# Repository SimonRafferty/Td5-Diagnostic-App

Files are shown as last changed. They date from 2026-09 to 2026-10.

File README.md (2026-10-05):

# Td5-Diagnostic-App

An open-source OBD2 scanner for Land Rover Td5 vehicles - live data, fault codes, and the parameters unique to the Td5, at a fraction of the cost of a NanoCom. Compatible with ELM327 apps, with its own built-in web app and an Android app.

An OBD2 scanner has become an essential part of most vehicle owners' toolkit. However, if you own a Land Rover Td5, your options are limited and expensive.

NanoCom from BlackBox Solutions is the go-to for most people, but it's pricey. If you want to re-map your engine it's good value - but most people just want to read live data and read/clear Diagnostic Trouble Codes (DTCs). On any other vehicle a simple ELM327 scanner and a phone app cost next to nothing; Td5 owners have had to fork out £600+ for a NanoCom. This project is a low-cost alternative - one you can leave in the Land Rover without worrying that it'll get wet, damaged or stolen.

Along with the matching hardware (a K-Line interface + ESP32-S3), it plugs into the Td5 diagnostic socket and emulates an ELM327 scanner. Unlike generic OBD2 apps, the app here also shows the information unique to the Td5, and reads and clears DTCs - completely free and open source.

## Updating your dongle

**[Click here to update your dongle to the latest firmware](https://simonrafferty.github.io/Td5-Diagnostic-App/flash/)**

Open the link in **Google Chrome** or **Microsoft Edge** on a computer, plug the dongle into the computer with a USB-C cable, and click **Install** - the page walks you through it in four simple steps. Updating keeps your stored fuel-economy history. (The version your dongle is running is shown at the bottom of the app.)

## Connecting to the Dongle

The dongle hosts the whole app itself, so the main way to use it is to open a web page it serves over its own WiFi - there's nothing to install.

### The main way - web page over WiFi (works on everything)

1. Connect your phone, tablet or PC to the open WiFi network **`OBDII`** (no password).
2. Open a browser and go to **http://11.1.1.1**.

That's it - the app loads straight from the dongle and connects itself. No app to install, no Bluetooth pairing. This works the same on **iPhone, iPad, Android and PC**.

> While you're on the dongle's WiFi your device has no internet, so online fault-code look-ups won't work. On Android you can connect over Bluetooth instead (see below) to keep your internet.

### iPhone and iPad

The WiFi web page above is the **only** way to connect on an iPhone or iPad - Safari can't use Bluetooth. Just join **`OBDII`** and open **http://11.1.1.1**; Safari handles it perfectly.

### Android - WiFi or the app

On Android you have two options:

- **Web page over WiFi** - exactly as above: join **`OBDII`** and open **http://11.1.1.1**. Nothing to install.
- **The Android app over Bluetooth** - install the [APK](Td5-Diagnostics-debug.apk) (see *Installing the Android App* below), open it, tap **Connect** and choose **OBDII**. Because this connects over Bluetooth, your phone stays on its normal mobile data, so online DTC look-ups keep working.

> The dongle serves **one connection at a time** - whichever you connect with first (WiFi or Bluetooth) is used for that session, and the other is disabled until the dongle restarts (which it does each time the engine starts).

## Installing the Android App

The app isn't on the Google Play Store yet - I'll upload it there in due course to make installing and updating easy. In the meantime you can "side-load" it directly, which only takes a minute:

1. On your Android phone or tablet, download [**Td5-Diagnostics-debug.apk**](Td5-Diagnostics-debug.apk) from this repository (open the link, then tap the download button).
2. Open it from your Downloads. Android will warn you it's from an "unknown source" - this is normal for any app installed outside the Play Store.
3. Follow the prompt to Settings and allow "Install unknown apps" for your browser (or Files app), then go back and tap Install.
4. Open Td5 Diagnostics, tap **Connect**, and choose **OBDII** from the list.

Because this is a debug build it isn't signed for the Play Store, so that "unknown source" warning is expected and safe to accept. Once the Play Store version is live I'll link to it from here (Google can take a while to approve an app).

## What the App Does

There are four simple tabs - swipe left and right to move between them:

- **Fault Codes** - read and clear DTCs, each with a plain-English description of the Td5 fault and a link to look it up online. Once connected it also shows the vehicle's VIN and current fuel-map name (where the ECU provides them).
- **Available Data** - every parameter the ECU will give you, including the extras unique to the Td5 - injector balance, accelerator tracks, EGR and wastegate, glow-plug and relay states, sensor voltages, idle-speed error and more - plus calculated values like turbo boost and live fuel economy (instantaneous, a rolling 50-mile average (paused while stationary), and trip fuel used). Tick what you'd like to see and/or graph, and pick your units.
- **Live Data** - your chosen parameters, updating live.
- **Graphs** - up to four auto-scaling charts so you can watch how things move (boost, temperatures, injector balance and so on).

### Logging

On the **Available Data** tab there's a single **Log displayed items to CSV** tick box. Tick it and everything you've chosen to display is written to a timestamped CSV file, in your selected units - handy for looking at a fault after a drive, or comparing readings over time.

- **In the Android app**, the file is saved straight to the phone's **Documents** folder as `Td5_Log_<date>_<time>.csv` (open it with the Files app, or copy it off over USB).
- **In the web page**, tick to start, then use **Download log now** - or simply untick - to save the file to your browser's Downloads.

## Screenshots

| Fault Codes | Available Data |
|:---:|:---:|
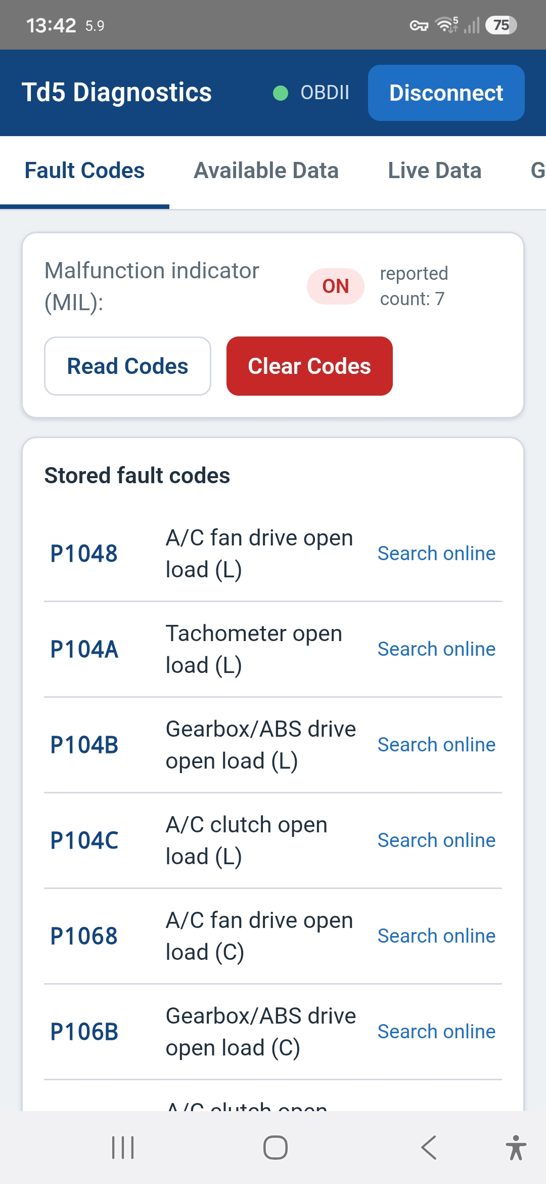
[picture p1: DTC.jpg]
Fault Codes screen
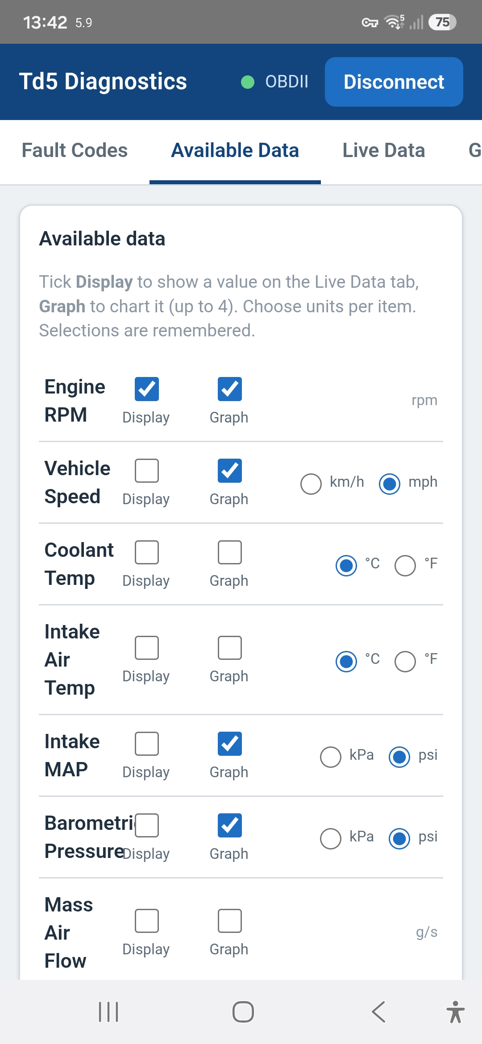
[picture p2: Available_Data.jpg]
Available Data screen
|  |  |
| **Live Data** | **Graphs** |
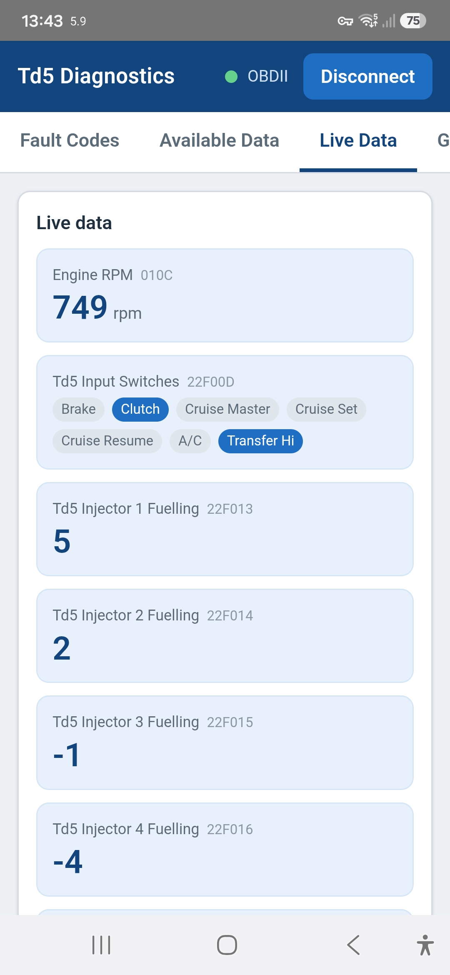
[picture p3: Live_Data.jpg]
Live Data screen
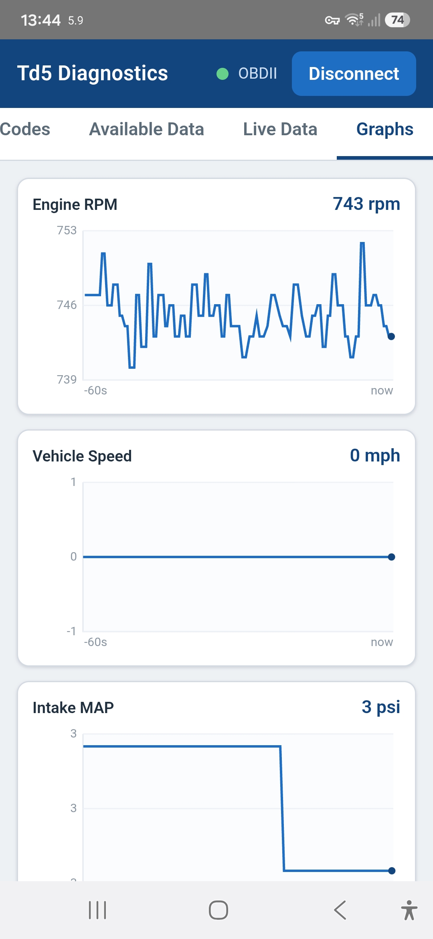
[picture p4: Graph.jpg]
Graphs screen
|  |  |

## What's in this Repository

| Item | Contents |
|---|---|
| `Firmware/` | The ESP32-S3 dongle firmware (Arduino). It turns the K-Line interface into an ELM327 that apps can talk to over **Bluetooth**, and also hosts the web app over **WiFi** (open `OBDII` network, http://11.1.1.1). |
| `App/` | The Android app project (built with Capacitor) used to produce the APK. |
| `Hardware/` | The complete dongle design: PCB gerbers, schematic, BOM, pick-and-place, Altium source, and 3D-printable case halves. |
| [`Td5-Diagnostics-debug.apk`](Td5-Diagnostics-debug.apk) | The ready-to-install Android app. |

## The Hardware

The dongle is an ESP32-S3 plus a simple K-Line interface (an L9637D transceiver and a little protection circuitry). It connects to the Td5 diagnostic line - OBD pin 7, or pin B18 on the ECU. Everything needed to build one is in the [`Hardware`](Hardware) folder:

- **PCB** - send [`Td5_OBD2_Gerber.zip`](Hardware/Td5_OBD2_Gerber.zip) to any board house to have the board made.
- **Assembly** - [`Td5_OBD2_BOM.csv`](Hardware/Td5_OBD2_BOM.csv) (bill of materials) and [`Td5_OBD2_PickAndPlace.xlsx`](Hardware/Td5_OBD2_PickAndPlace.xlsx).
- **Design source** - the full [schematic (PDF)](Hardware/Td5_OBD2_Schematic.pdf) and the editable [Altium project](Hardware/Td5_OBD2_Altium.zip).
- **Enclosure** - two 3D-printable case halves: [left](Hardware/Dongle%203D%20Print%20Shell%20Left.STEP) and [right](Hardware/Dongle%203D%20Print%20Shell%20Right.STEP) (STEP).

## Building From Source

**Firmware:** open `Firmware/Td5_Diagnostic/Td5_Diagnostic.ino` in the Arduino IDE, select the **XIAO_ESP32S3** board and upload. You'll need the *EspSoftwareSerial* and *NimBLE-Arduino* libraries (WiFi and DNSServer are built into the ESP32 core). The web app the dongle serves over WiFi is embedded as `webapp_html.h`, already in the repo, so it builds as-is. If you change the app, regenerate that header with `python Firmware/tools/embed_webapp.py` before rebuilding.

**Publishing a firmware update** to the web flasher: run `python Firmware/tools/publish_firmware.py`. It stamps a date-based version into `config.h`, re-embeds the app, compiles against the Arduino IDE's sketchbook libraries and copies the four flash images plus `manifest.json` into `flash/`. Commit and push, and the update page serves the new version about a minute later.

**Android app:** the app is `App/www/index.html` plus a small Bluetooth bridge that lets the native APK reach the phone's Bluetooth stack (an Android WebView has no Web Bluetooth). To rebuild the APK, run `npm install` in the `App` folder, then `npm run sync`, and build with Android Studio (or `gradlew assembleDebug`).

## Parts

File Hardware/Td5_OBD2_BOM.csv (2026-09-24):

No. | Quantity | Comment | Designator | Footprint | Value | Manufacturer Part | Manufacturer | Supplier Part | Supplier
1 | 3 | 330nF | C1,C2,C3 | C0603 | 330nF | TCC0603X7R334K500CT | CCTC(三环) | C282682 | LCSC
2 | 1 | 100nF | C4 | C0402 | 100nF | CC0402KRX7R7BB104 | YAGEO(国巨) | C60474 | LCSC
3 | 1 | ZMM27V | D1 | LL-34_L3.5-W1.5-RD |  | ZMM27V | JSMSEMI(杰盛微) | C2857252 | LCSC
4 | 2 | SS34 | D2,D3 | SMA_L4.3-W2.6-LS5.2-RD |  | SS34 | MDD(辰达半导体) | C8678 | LCSC
5 | 1 | OBD2 | J*1 | OBD2_Male_R/A_Case https://www.aliexpress.com/item/1005006438089634.html
6 | 1 | 47kΩ | R1 | R0402 | 47kΩ | 0402WGF4702TCE | UNI-ROYAL(厚声) | C25792 | LCSC
7 | 1 | 1kΩ | R2 | R0603 | 1kΩ | FRC0603F1001TS | FOJAN(富捷) | C2907002 | LCSC
8 | 1 | 510R | R3 | R0603
9 | 1 | 10kΩ | R4 | R0402 | 10kΩ | FRC0402F1002TS | FOJAN(富捷) | C2906861 | LCSC
10 | 1 | 51kΩ | R5 | R0402 | 51kΩ | 1RC0402J0513 | SAE(世盟/世爱) | C54531106 | LCSC
11 | 1 | 20kΩ | R6 | R0402 | 20kΩ | TNPW040220K0BEED | VISHAY(威世) | C844261 | LCSC
12 | 1 | TLV3691IDCKR | U1 | SC-70-5_L2.1-W1.3-P0.65-LS2.1-BR |  | TLV3691IDCKR | TI(德州仪器) | C180352 | LCSC
13 | 1 | K7805-500R3 | U2 | PWRM-TH_3P-L11.5-W7.6-P2.54_R-785.0-0.5 |  | K7805-500R3 | YLPTEC(易川) | C2992390 | LCSC
14 | 1 | E-L9637D013TR | U3 | SOIC-8_L4.9-W3.9-P1.27-LS6.0-BL |  | E-L9637D013TR | ST(意法半导体) | C153038 | LCSC
15 | 1 | XIAO ESP32S3 | U4 | COMM-SMD_KQ-2801_V106 |  | XIAO ESP32C3 | null | C19189385 | LCSC

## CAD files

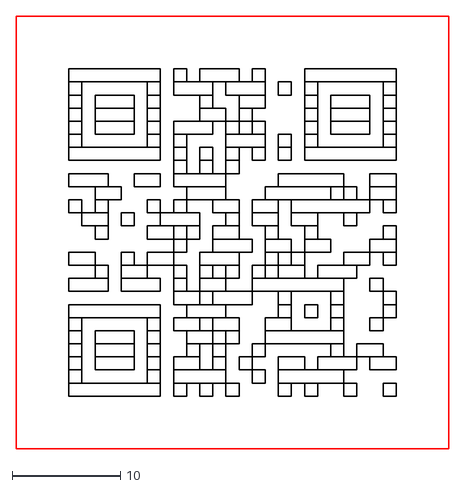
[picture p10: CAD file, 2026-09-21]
Hardware/Td5_QR_Code.dxf
40.0 x 40.0

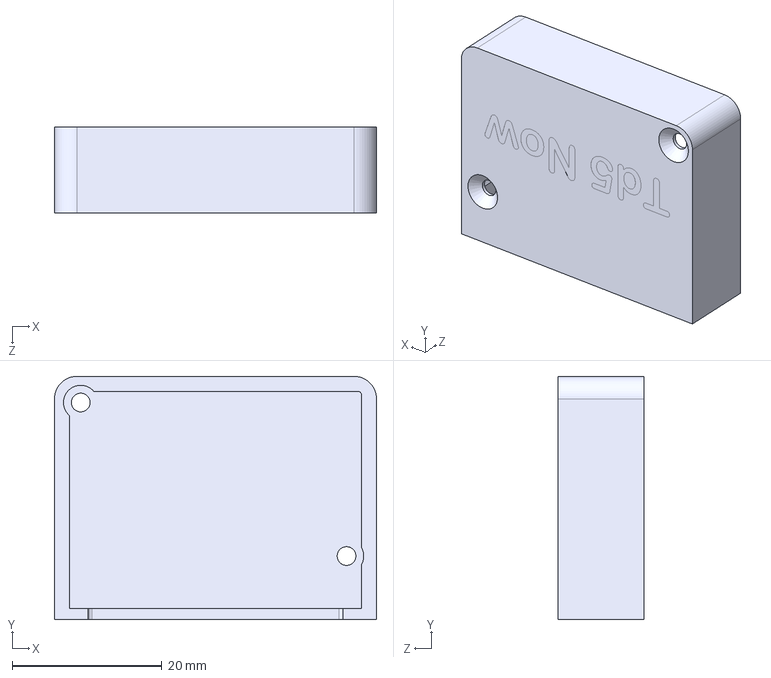
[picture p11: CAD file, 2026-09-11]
Hardware/Dongle 3D Print Shell Right.STEP
43.0 x 32.5 x 11.5 mm

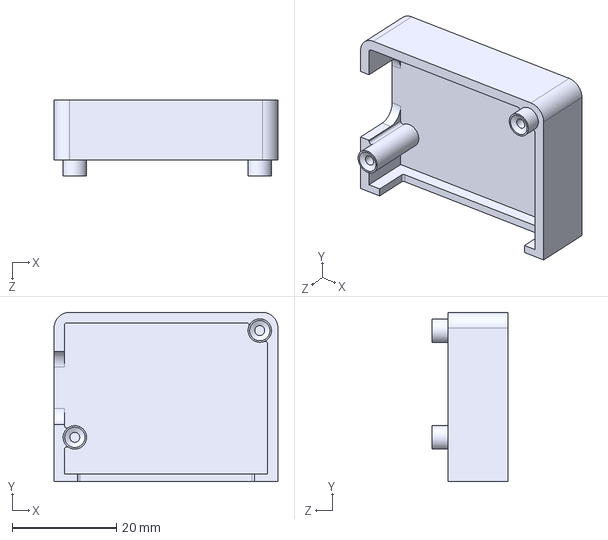
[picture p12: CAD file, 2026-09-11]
Hardware/Dongle 3D Print Shell Left.STEP
43.0 x 32.5 x 14.5 mm

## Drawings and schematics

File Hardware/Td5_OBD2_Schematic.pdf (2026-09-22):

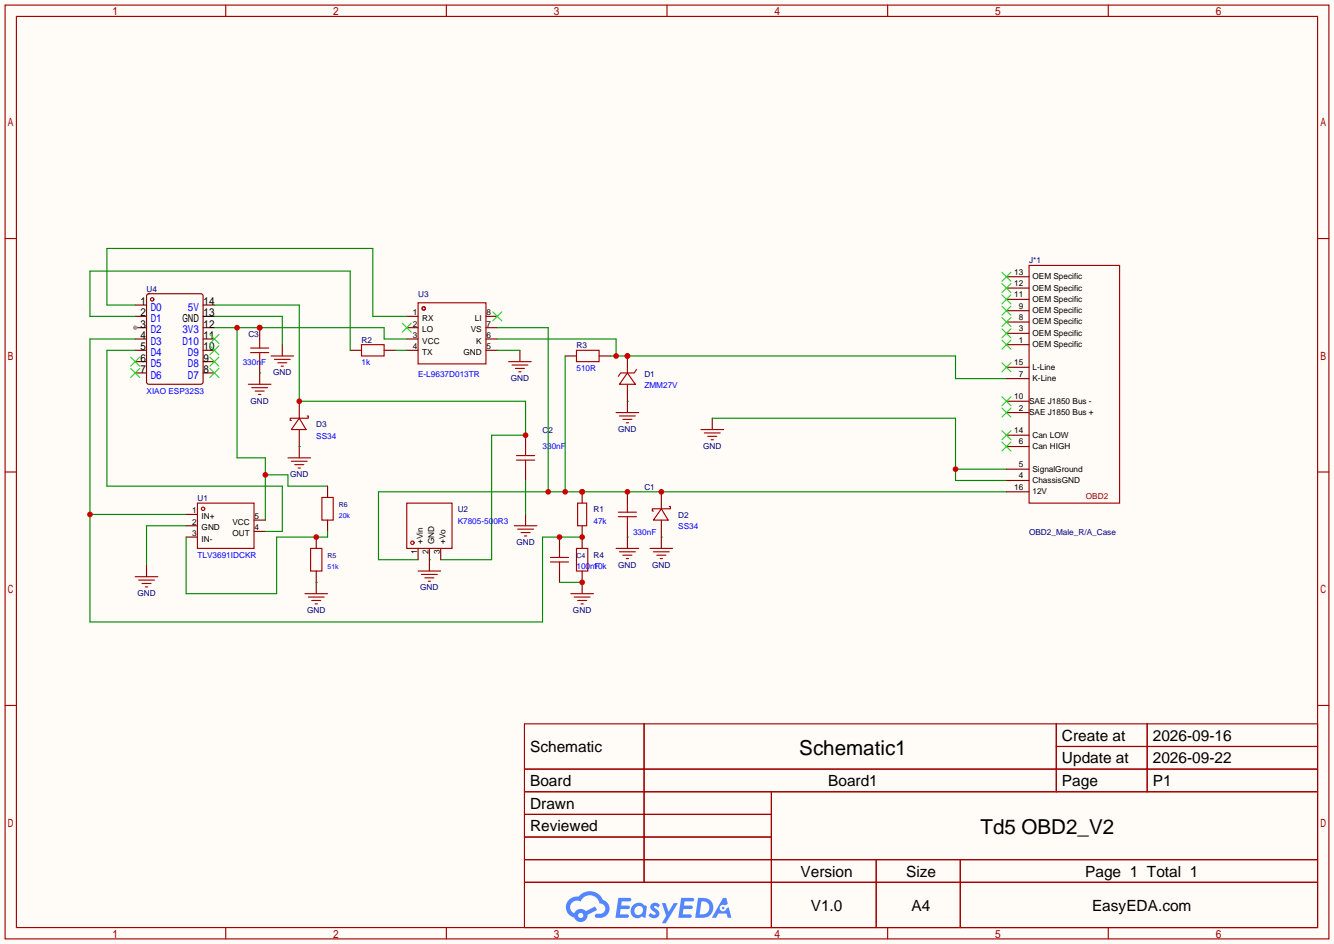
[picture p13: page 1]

Schematic | Schematic1 | Create at | 2026-09-16

Update at | 2026-09-22

Board | Board1 | Page | P1
Drawn | | Td5 OBD2_V2
Reviewed

Version | Size | Page 1 Total 1
V1.0 | A4 | EasyEDA.com

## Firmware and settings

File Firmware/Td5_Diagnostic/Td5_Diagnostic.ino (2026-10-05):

/*
 * Td5_Diagnostic_V2.ino - Land Rover Td5 Diagnostic (ELM327) dongle - V2 hardware
 * ===============================================================================
 *
 * Identical to Td5_Diagnostic EXCEPT for the V2 PCB power management. The ECU /
 * ELM327 / BLE / OBD stack is UNCHANGED - keep it in sync with Td5_Diagnostic;
 * any protocol/decode change must be applied to BOTH sketches.
 *
 * V2 power management (comparator-gated deep sleep, ported from Td5_ESPNow_V2):
 *   - D3 (GPIO4) = battery-divider sense (ADC, x5.7). Serial-debug only.
 *   - D4 (GPIO5) = TLV3691 comparator output, HIGH when Vbat > ~13.5V
 *                  (engine started / alternator charging). EXT0 deep-sleep wake.
 *   - Wake  : deep sleep -> D4 rising HIGH (engine start).
 *   - Sleep : after INACTIVITY_TIMEOUT_MS (5 min) of no ECU comms AND D4 == LOW.
 *   The dongle wakes on ENGINE START, not ignition-on alone (~12.4V keeps D4 LOW).
 *
 * Pin assignments CONFIRMED on the V2 PCB (2026-09-20): D3=GPIO4 (PIN_VBAT_SENSE),
 * D4=GPIO5 (PIN_CHG_SENSE) - see config.h.
 * Set ENABLE_DEEP_SLEEP 0 in config.h for bench work on hardware without the
 * comparator (a floating D4 could otherwise trigger a random sleep).
 *
 * Board: Seeed XIAO ESP32-S3   FQBN: esp32:esp32:XIAO_ESP32S3
 */

#include "config.h"
#include "vehicle_data.h"
#include "data_provider.h"
#include "obd_pids.h"
#include "elm327.h"

#if ENABLE_DEEP_SLEEP
  #include <esp_sleep.h>          // deep sleep + wake-cause
  #include "driver/rtc_io.h"      // rtc_gpio_* (wake-pin pull config)
#endif

#include "transport_arbiter.h"
#if ENABLE_WIFI_ELM
  #include "wifi_server.h"
#endif
#if ENABLE_WIFI_WEBAPP
  #include "web_server.h"
#endif
#if ENABLE_BLE_ELM
  #include "ble_server.h"
#endif

#if !ENABLE_WIFI_ELM && !ENABLE_WIFI_WEBAPP && !ENABLE_BLE_ELM
  #error "Enable at least one transport (ENABLE_BLE_ELM / ENABLE_WIFI_WEBAPP / ENABLE_WIFI_ELM) in config.h"
#endif

#if DATA_SOURCE_SIM
  #include "sim_provider.h"
  static SimProvider provider;
#else
  #include "td5_provider.h"
  static Td5Provider provider;
#endif

// The stack above the provider is identical in both phases and both transports.
static ObdTranslator obd(provider);
static Elm327        elm(obd);

// One-radio-per-session lock shared by the BLE and WiFi servers (transport_arbiter.h).
static TransportArbiter arbiter;

#if ENABLE_WIFI_ELM
static WifiElmServer wifiServer(elm, ELM_TCP_PORT);
#endif
#if ENABLE_WIFI_WEBAPP
static WebAppServer  webServer(elm, arbiter, WEBAPP_HTTP_PORT);
#endif
#if ENABLE_BLE_ELM
static BleElmServer  bleServer(elm, arbiter);
#endif

// ============================================================================
// V2 POWER MANAGEMENT (comparator-gated deep sleep)
// ============================================================================
#if ENABLE_DEEP_SLEEP

// RTC memory survives deep sleep; reset only on a true power cycle.
RTC_DATA_ATTR uint32_t bootCount = 0;

// Single activity timestamp driving the sleep decision. Reset on ECU comms / charging.
static unsigned long lastActivityMs = 0;

// Power-management runtime state (all session-only; nothing persisted to flash).
static uint16_t g_vbatMv    = 0;      // latest measured battery voltage (mV), refreshed ~2s
static bool     g_fromSleep = false;  // this boot woke from deep sleep (vs a true power-on)
static bool     g_compOk    = false;  // D4 reads LOW while off-charge (healthy) - diagnostic/display only

// Battery voltage on D3 (GPIO4) via the 47k/10k divider, in millivolts.
// Diagnostic / Serial only - never enters the OBD data path.
static uint16_t readBatteryVoltage() {
  uint32_t acc = 0;
  for (uint8_t i = 0; i < VBAT_ADC_SAMPLES; i++)
    acc += analogReadMilliVolts(PIN_VBAT_SENSE);   // eFuse-calibrated mV at the pin
  return (uint16_t)(((float)acc / VBAT_ADC_SAMPLES) * VBAT_DIVIDER_RATIO);
}

// Called only once the engine is judged off (Vbat < CHARGE_MV, ECU quiet). The WAKE
// source is decided from the LIVE comparator level read here:
//   D4 LOW  -> healthy: wake on the D4 rising edge (engine start) + a long backstop
//   D4 HIGH -> can't trust it (stuck-high fault, or genuinely charging): poll in 10s
static void enterSleepMode() {
#if ENABLE_WIFI_ELM || ENABLE_WIFI_WEBAPP
  WiFi.disconnect(true);
  WiFi.mode(WIFI_OFF);          // kill the AP radio before sleeping (covers the web-app AP too)
#endif
  esp_sleep_disable_wakeup_source(ESP_SLEEP_WAKEUP_ALL);   // clean slate - RTC config survives sleep

  if (digitalRead(PIN_CHG_SENSE) == LOW) {
    Serial.printf("\n*** Deep sleep (Boot #%u) -> wake on engine start (D4 rising), %lumin backstop ***\n",
                  bootCount, (unsigned long)(LONG_SLEEP_US / 60000000ULL));
    Serial.flush();
    esp_sleep_enable_ext0_wakeup(PIN_CHG_SENSE, 1);   // D4 is LOW now -> fires on the LOW->HIGH edge
    rtc_gpio_pullup_dis(PIN_CHG_SENSE);               // TLV3691 is push-pull; no internal pull
    rtc_gpio_pulldown_dis(PIN_CHG_SENSE);
    esp_sleep_enable_timer_wakeup(LONG_SLEEP_US);      // safety backstop only
  } else {
    Serial.printf("\n*** Deep sleep (Boot #%u) -> re-check in %lus (D4 HIGH, can't wake on it) ***\n",
                  bootCount, (unsigned long)(SHORT_SLEEP_US / 1000000ULL));
    Serial.flush();
    esp_sleep_enable_timer_wakeup(SHORT_SLEEP_US);
  }

  esp_deep_sleep_start();   // ESP32 resets on wake - never returns
}

// Sleep after INACTIVITY_TIMEOUT_MS of no ECU comms AND battery voltage below the
// charge threshold. The decision uses the accurate D3 reading, not the comparator.
static void checkSleepCondition() {
  // Stay awake while the alternator is charging (engine running) or the ECU is
  // still responding; keep the inactivity window fresh so a full timeout is only
  // needed once the engine actually stops.
  if (g_vbatMv >= CHARGE_MV || provider.connected()) {
    lastActivityMs = millis();
    return;
  }
  if (millis() - lastActivityMs > INACTIVITY_TIMEOUT_MS) {
    Serial.println(F("\n*** Engine off (Vbat low) + inactivity timeout - sleeping ***"));
    enterSleepMode();  // does not return
  }
}

static void vbatDebug() {
  static unsigned long lastVbatMs = 0;
  if (millis() - lastVbatMs >= VBAT_READ_INTERVAL_MS) {
    lastVbatMs = millis();
    uint16_t mv = readBatteryVoltage();
    g_vbatMv = mv;
    int d4 = digitalRead(PIN_CHG_SENSE);

    // Track comparator health for the diagnostic display only: when clearly parked
    // (off-charge), a healthy D4 reads LOW. Session-only, not persisted; the sleep
    // path reads the comparator live rather than trusting this flag.
    if (mv > 1000 && mv < LOW_BATT_MV) {
      bool ok = (d4 == LOW);
      if (ok != g_compOk) {
        g_compOk = ok;
        Serial.printf("[PWR] comparator %s off-charge -> %s wake\n",
                      ok ? "reads LOW (healthy)" : "stuck HIGH (faulty)",
                      ok ? "D4-edge" : "10s poll");
      }
    }

#if ENABLE_VBAT_DEBUG
    Serial.printf("[VBAT] D3: %u mV (%.2f V) | D4: %s | comp: %s | ECU: %s\n",
                  mv, mv / 1000.0f,
                  d4 ? "HIGH" : "low",
                  g_compOk ? "healthy" : "faulty",
                  provider.connected() ? "connected" : "-");
#endif
  }
}

static void powerMgmtSetup() {
  pinMode(PIN_CHG_SENSE, INPUT);                      // comparator out - external push-pull, no pulls
  pinMode(PIN_VBAT_SENSE, INPUT);
  analogSetPinAttenuation(PIN_VBAT_SENSE, ADC_11db);  // full-scale ~0..3.3V
  analogReadResolution(12);

  bootCount++;
  esp_sleep_wakeup_cause_t wake = esp_sleep_get_wakeup_cause();
  g_fromSleep = (wake == ESP_SLEEP_WAKEUP_TIMER || wake == ESP_SLEEP_WAKEUP_EXT0);
  g_vbatMv = readBatteryVoltage();

  const char* wc = wake == ESP_SLEEP_WAKEUP_TIMER ? "TIMER"
                 : wake == ESP_SLEEP_WAKEUP_EXT0  ? "EXT0 (engine start)"
                                                  : "power-on / reset";
  Serial.printf("Boot #%u - wake: %s - Vbat %.2fV\n", bootCount, wc, g_vbatMv / 1000.0f);
  lastActivityMs = millis();   // start the inactivity window
}

#endif // ENABLE_DEEP_SLEEP

void setup() {
  Serial.begin(DEBUG_BAUD);
  Serial.setTxTimeoutMs(0);   // never block on debug prints if no USB reader attached
  delay(300);
  Serial.println();
  Serial.println(F("=== Td5 Diagnostic (ELM327) - V2 (deep sleep) ==="));
  Serial.println(F("Firmware version: " FW_VERSION));
#if DATA_SOURCE_SIM
  Serial.println(F("Data source: SIMULATED (Phase 1 bench)"));
#else
  Serial.println(F("Data source: REAL Td5 ECU (Phase 2)"));
#endif
#if ENABLE_BLE_ELM
  Serial.println(F("Transport: BLE (advertising as \"" BLE_DEVICE_NAME "\")"));
#endif
#if ENABLE_WIFI_ELM
  Serial.println(F("Transport: WiFi AP (Torque TCP)"));
#endif
#if ENABLE_WIFI_WEBAPP
  Serial.println(F("Transport: WiFi web app (SoftAP \"" AP_SSID "\" @ 11.1.1.1, open)"));
#endif

#if ENABLE_DEEP_SLEEP
  powerMgmtSetup();
  // Woke from deep sleep but still off-charge (parked): go straight back to sleep
  // without spinning up BLE / K-line, to keep average power low.
  if (g_fromSleep && g_vbatMv < CHARGE_MV) {
    Serial.println(F("Woke off-charge -> back to sleep"));
    enterSleepMode();  // does not return
  }
#endif

  provider.begin();
#if ENABLE_WIFI_ELM
  wifiServer.begin();
#endif
#if ENABLE_WIFI_WEBAPP
  webServer.begin();    // SoftAP + captive portal + HTTP app host (shares the radio with BLE)
#endif
#if ENABLE_BLE_ELM
  bleServer.begin();
#endif
}

void loop() {
  provider.poll();      // refresh live values (non-blocking; K-line runs in its own task)
#if ENABLE_WIFI_ELM
  wifiServer.poll();    // service the WiFi ELM327 session (Torque)
#endif

  // One-radio-per-session: the first transport to get a real app connection wins;
  // shut the other down (idempotent) and keep it down until the next wake/reboot.
  // All radio teardown happens here in the main task - never in a NimBLE callback.
  Transport a = arbiter.active();
#if ENABLE_BLE_ELM
  if (a == T_WIFI) bleServer.stop();     // WiFi won -> stop BLE
  else             bleServer.poll();     // (no-op; replies are inline)
#endif
#if ENABLE_WIFI_WEBAPP
  if (a == T_BLE)  webServer.shutdown(); // BLE won -> stop the WiFi AP
  else             webServer.poll();     // serve DNS + HTTP
#endif

#if ENABLE_DEEP_SLEEP
  vbatDebug();          // periodic Serial battery print (diagnostic only)
  checkSleepCondition();// may enter deep sleep (does not return)
#endif
}

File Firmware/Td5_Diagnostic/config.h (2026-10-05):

/*
 * config.h - Build-time configuration for the Td5 Diagnostic ELM327 dongle (V2)
 *
 * ONE FLAG controls the whole build phase:
 *   DATA_SOURCE_SIM 1  -> Phase 1 (bench): synthetic data, no ECU needed
 *   DATA_SOURCE_SIM 0  -> Phase 2 (vehicle): real Td5 K-Line data
 *
 * V2 adds comparator-gated deep sleep for the new PCB (see bottom of file).
 * Everything else (WiFi, ELM327 emulation, OBD translation) is identical to V1.
 */

#ifndef TD5_TORQUE_CONFIG_H
#define TD5_TORQUE_CONFIG_H

// ---------------------------------------------------------------------------
// Phase selector
// ---------------------------------------------------------------------------
#define DATA_SOURCE_SIM   0        // 1 = simulated (bench), 0 = real Td5 ECU

// ---------------------------------------------------------------------------
// Transport selector - how the phone talks to the dongle
// ---------------------------------------------------------------------------
// BLE keeps the phone on its normal WiFi/cellular internet (so online DTC
// lookups work); the WiFi AP does not. You can enable either or both, but for
// the "keep internet" goal run BLE-only (the phone must NOT join the AP).
//   BLE  works with Car Scanner / OBD Fusion (BLE-native) and *maybe* Torque.
//   WiFi is the guaranteed-Torque fallback (192.168.0.10:35000).
#define ENABLE_BLE_ELM    1        // 1 = advertise as a BLE ELM327
#define ENABLE_WIFI_ELM   0        // 1 = also run the WiFi AP + TCP server (Torque; legacy)

// Browser-over-WiFi: the dongle hosts the web app and answers ELM over plain HTTP,
// so iOS Safari (no Web Bluetooth) and any browser can use it. Shares the SoftAP.
#define ENABLE_WIFI_WEBAPP    1    // 1 = SoftAP + HTTP server hosting the app + POST /elm bridge
#define ENABLE_CAPTIVE_PORTAL 0    // removed - a JS app can't run in the OS captive mini-browsers
#define WEBAPP_HTTP_PORT      80

#define BLE_DEVICE_NAME   "OBDII"  // generic name every OBD app recognises

// ---------------------------------------------------------------------------
// Debug
// ---------------------------------------------------------------------------
#define DEBUG_SERIAL      1        // 1 = print ELM traffic + status to USB serial
#define DEBUG_BAUD        115200
#define TD5_DEBUG_FRAMES  1        // Phase 2 only: log every raw ECU response frame
                                   // (sub-PID + bytes) to USB serial. Set 0 once
                                   // live values are validated on the vehicle.

// ---------------------------------------------------------------------------
// WiFi Access Point (the phone joins this network)
// ---------------------------------------------------------------------------
// Torque's WiFi OBD default is IP 192.168.0.10, port 35000. We match that so
// the user only has to pick "Bluetooth/WiFi -> WiFi" in Torque with defaults.
#define AP_SSID           "OBDII"        // hotspot name (matches the BLE name + the join QR)
#define AP_PASS           ""             // "" = OPEN network (no password); >= 8 chars for WPA2 otherwise
#define AP_CHANNEL        6
// Number of WiFi *associations* the AP allows. Must be >1 so a debug PC and the
// phone can both be joined; the single-session nature of ELM327 is enforced at
// the TCP layer (see WifiElmServer), NOT by limiting WiFi stations.
#define AP_MAX_CLIENTS    4

#define ELM_AP_IP_0       11
#define ELM_AP_IP_1       1
#define ELM_AP_IP_2       1
#define ELM_AP_IP_3       1              // ESP32 = 11.1.1.1 (short, printable on the case; clear of every
                                         // host interface: 10.0.0 GL.iNet / 192.168.4 / 192.168.1 / 172.22)
#define ELM_TCP_PORT      35000

// ---------------------------------------------------------------------------
// ELM327 identity (what the emulator reports for ATZ / ATI)
// ---------------------------------------------------------------------------
// v1.5 is the safest, most widely-compatible version string for Torque.
// Firmware release version (date-based). Set by Firmware/tools/publish_firmware.py,
// which also stamps it into the web flasher's manifest. Reported by AT@2.
#define FW_VERSION        "2026-10-05"

#define ELM_VERSION       "ELM327 v1.5"
#define ELM_DESCRIPTION   "OBDII to RS232 Interpreter"

// ---------------------------------------------------------------------------
// Phase 2 (real ECU) - K-Line pins on the XIAO ESP32-S3
// (Reused verbatim from the Td5_ESPNow project. Unused when DATA_SOURCE_SIM.)
// ---------------------------------------------------------------------------
#if !DATA_SOURCE_SIM
  #define KLINE_TX_PIN    2      // D1 on silkscreen (via 1k to L9637D)
  #define KLINE_RX_PIN    1      // D0 on silkscreen (direct from L9637D)
#endif
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

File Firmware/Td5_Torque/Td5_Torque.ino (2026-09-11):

/*
 * Td5_Torque.ino - Land Rover Td5 -> Torque (ELM327-over-WiFi) dongle
 * ===================================================================
 *
 * Presents the ESP32 as a WiFi ELM327 OBD-II adapter so the Torque app (and
 * other ELM327 apps) can display live data and read/clear fault codes.
 *
 *   Phone  --WiFi-->  ESP32 SoftAP "Td5-Torque"  (192.168.0.10:35000)
 *          --TCP-->   WifiElmServer -> Elm327 -> ObdTranslator -> DataProvider
 *
 * Phase is chosen by ONE flag in config.h:
 *   DATA_SOURCE_SIM 1  -> SimProvider  (bench: synthetic data + fake DTCs)
 *   DATA_SOURCE_SIM 0  -> Td5Provider  (vehicle: real K-Line data)  [Phase 2]
 *
 * Board: Seeed XIAO ESP32-S3   FQBN: esp32:esp32:XIAO_ESP32S3
 *
 * See README_SETUP.md for Torque configuration and Td5_Torque_PIDs.csv for the
 * importable custom-PID definitions.
 */

#include "config.h"
#include "vehicle_data.h"
#include "data_provider.h"
#include "obd_pids.h"
#include "elm327.h"

#if ENABLE_WIFI_ELM
  #include "wifi_server.h"
#endif
#if ENABLE_BLE_ELM
  #include "ble_server.h"
#endif

#if !ENABLE_WIFI_ELM && !ENABLE_BLE_ELM
  #error "Enable at least one transport (ENABLE_BLE_ELM or ENABLE_WIFI_ELM) in config.h"
#endif

#if DATA_SOURCE_SIM
  #include "sim_provider.h"
  static SimProvider provider;
#else
  #include "td5_provider.h"     // created in Phase 2
  static Td5Provider provider;
#endif

// The stack above the provider is identical in both phases and both transports.
static ObdTranslator obd(provider);
static Elm327        elm(obd);
#if ENABLE_WIFI_ELM
static WifiElmServer wifiServer(elm, ELM_TCP_PORT);
#endif
#if ENABLE_BLE_ELM
static BleElmServer  bleServer(elm);
#endif

void setup() {
  Serial.begin(DEBUG_BAUD);
  Serial.setTxTimeoutMs(0);   // never block on debug prints if no USB reader attached
  delay(300);
  Serial.println();
  Serial.println(F("=== Td5 -> Torque (ELM327 over WiFi) ==="));
#if DATA_SOURCE_SIM
  Serial.println(F("Data source: SIMULATED (Phase 1 bench)"));
#else
  Serial.println(F("Data source: REAL Td5 ECU (Phase 2)"));
#endif
#if ENABLE_BLE_ELM
  Serial.println(F("Transport: BLE (advertising as \"" BLE_DEVICE_NAME "\")"));
#endif
#if ENABLE_WIFI_ELM
  Serial.println(F("Transport: WiFi AP"));
#endif

  provider.begin();
#if ENABLE_WIFI_ELM
  wifiServer.begin();
#endif
#if ENABLE_BLE_ELM
  bleServer.begin();
#endif
}

void loop() {
  provider.poll();      // refresh live values (non-blocking)
#if ENABLE_WIFI_ELM
  wifiServer.poll();    // service the WiFi ELM327 session
#endif
#if ENABLE_BLE_ELM
  bleServer.poll();     // service the BLE ELM327 session
#endif
}

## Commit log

2026-09-11 Add firmware, Android app source and installable APK
    - Firmware/Td5_Torque: ESP32-S3 dongle firmware (BLE ELM327 for the Td5 K-line)
    - App: Capacitor Android project (source) that builds the APK
    - Td5-Diagnostics-debug.apk: ready-to-side-load Android app
    - Hardware/: placeholder for the PCB gerbers (to be added)
    - README: side-load instructions, repo contents, build-from-source
    [Td5_Torque_PIDs.csv]
2026-09-11 Rename Td5_Torque -> Td5_Diagnostic; link the APK in the README
    The project never worked with the Torque app, so 'Torque' is dropped from the name.
    Renamed the firmware sketch (folder, .ino, _PIDs.csv) and updated all project-name
    references (incl. the WiFi SSID Td5-Torque -> Td5-Diagnostic). Kept genuine references
    to the external Torque app and to the engine 'torque limit' parameter. README now links
    Td5-Diagnostics-debug.apk to its location in the repo.
    [Td5_Diagnostic_PIDs.csv]
2026-09-11 docs: browser/hosting instructions + drop Td5_ESPNow_Torque from build paths
    README: clarify the web app runs in a browser (GitHub Pages link or local file://),
    correct the iOS/Bluefy hosting note. README_SETUP: repo-relative build path (removes the
    last 'Torque' from the name).
2026-09-11 Add files via upload
    3D Printable shells for the Td5 OBD2 Dongle
    [Dongle 3D Print Shell Left.STEP, Dongle 3D Print Shell Right.STEP]
2026-09-11 docs: Hardware is now uploaded - list & link PCB/schematic/BOM/Altium/3D-print files
2026-09-12 fix: correct schematic filename typo (Scematic -> Schematic) and update README link
2026-09-20 feat: MEMSTools-decoded parameters, fuel economy + CSV logging
    Firmware (Td5_Diagnostic):
    - Correct 0x1A (temps + sensor voltages) / 0x1C (MAP + MAF) decode; fix 0x1D smoke/torque swap
    - Add relay/output status (0x36), EGR inlet throttle (0x45), idle speed error (0x21),
    ignition + security link; battery/ambient "direct reading" values
    - Read VIN (1A 87), map/fuel/homologation (21 32) and accelerator pedal type (0x20 bit7)
    - New fuel_economy.h: instant + rolling 10-mile-average MPG/L-100km + trip fuel, NVS-persisted
    - Expose everything via mode 22 DIDs 0xF018-0xF02C, VIN via mode 09
    App:
    - New Available Data items (fuel economy, sensor voltages, relay/output states, EGR inlet,
    idle error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
    [Td5_Diagnostic_PIDs.csv]
2026-09-20 fix+polish: freeze on data-stop, correct MIL, no greying, grouped item order
    - Available/Live data items regrouped (engine, fuelling, economy, air, temps,
    sensor voltages, accelerator, actuators, injectors, switches, relay, electrical)
    - Nothing greyed out - all values shown as available/selectable
    - Graphs freeze their window when data stops (last trace stays visible)
    - Dongle returns NO DATA once the ECU disconnects, so the app freezes the last
    reading instead of some values falling to zero
    - MIL indicator corrected: the 0x36 MIL drive is active-low (was showing lit
    when the dash lamp was off)
    Rebuilt APK + single-file PWA. (V2 deep-sleep build kept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
    [td5_provider.cpp]
2026-09-21 hardware: add case QR code (DXF + preview) linking to psi-design.co.uk/td5/
    [Td5_QR_Code.dxf]
2026-09-22 firmware: replace V1 with the vehicle-proven V2 deep-sleep firmware
    V2 becomes the sole firmware (V1 retired). The only differences from V1 were the
    power management, so this adds to Firmware/Td5_Diagnostic/:
    - config.h: D3 battery-sense / D4 comparator pins + voltage-based sleep
    thresholds (CHARGE_MV, LOW_BATT_MV, SHORT/LONG_SLEEP_US)
    - Td5_Diagnostic.ino: voltage-driven deep sleep - sleeps when the engine is off,
    wakes on the D4 comparator (engine start) when it's usable, and falls back to a
    10s voltage poll otherwise
    Folder and sketch name kept as Td5_Diagnostic so existing README links still work.
    [Td5_Diagnostic.ino, config.h]
2026-09-23 fix(app): dongle copy is HTTP-only + Td5 indicator + self-healing connect
    The copy the dongle serves over WiFi could fall through to Web Bluetooth, which
    grabbed the session and shut its own WiFi AP down (the SSID vanished). embed_webapp.py
    now bakes FORCE_HTTP=true into that copy so it never tries BLE, auto-connects, and
    hides the Connect button. The GitHub/HTTPS copy is unchanged (still Web Bluetooth).
    Also:
    - a "Td5" indicator in the header - green when ECU data is flowing, amber when the
    dongle is up but the ECU isn't answering yet, grey when the link is down
    - a 2s supervisor that keeps the dongle connection + polling alive, so live data
    flows whenever the ECU becomes avail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
2026-09-23 fix(firmware): MIL badge reflects the dash lamp, not the stored-code count
    The Fault-Codes MIL badge (OBD 0101 bit7) was set whenever any DTCs were stored
    (cnt ? 0x80 : 0). The Td5 keeps historic/intermittent codes that don't light the
    dash lamp, so the badge was permanently on. It now reads the actual MIL lamp output
    (d.milOn, PID 0x36 bit4); bits0-6 still carry the stored-code count.
    Also corrected the 0x36 MIL polarity to active-high (`(r1 & 0x10) != 0`) - the bit
    reads 0 with the dash lamp off (vehicle-observed), so the earlier "active-low" guess
    was wrong. Badge + relay/output "MIL" item now agree with the dash.
    [td5_provider.cpp]
2026-09-23 build(apk): rebuild Android app with the current UI (Td5 indicator + self-healing connect)
    The Capacitor source (App/www/index.html) had fallen behind the browser app. It's now
    regenerated from Td5-Diagnostic.html plus the ble-shim.js BLE bridge, so the native app
    picks up the Td5 connection indicator and the auto-recovering connect. Rebuilt
    Td5-Diagnostics-debug.apk (installed + verified on device). BLE-only path - the WiFi/HTTP
    transport bits are inert in the native app (isNative -> Bluetooth).
2026-09-24 Update Td5_OBD2_BOM.csv
    Added link to OBD2 Connector
    [Td5_OBD2_BOM.csv]
2026-09-24 Td5 diagnostics: X-Y DTC codes, 11.1.1.1 AP, deep-sleep firmware, rebuilt APK/PWA
    Firmware:
    - DTCs reported as raw Lucas X-Y codes over mode 03 (the app looks up the
    description) instead of packed OBD P-codes.
    - SoftAP moved to 11.1.1.1 (short/printable, clear of common home subnets).
    - Deep sleep enabled for the vehicle: comparator-gated, wakes on engine start,
    sleeps ~5 min after the engine stops.
    - Embedded web app re-synced to match the PWA/APK.
    - "Selected Gear" hidden - the Td5 engine ECU doesn't report it (the XYZ switch
    feeds the auto/EAT ECU). Code retained, commented out.
    - sendNow() error-path fix: clear the pending timeout before nulling the record.
    Rebuilt the PWA (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
    [Td5_Diagnostic.ino, config.h, td5_provider.cpp]
2026-09-24 Restore ble-shim.js (native BLE bridge) - required for the Capacitor APK build
2026-09-24 tidy: drop the stale "standalone browser build" comment; rebuild APK
    Removes the leftover comment above the ble-shim <script> in App/www/index.html that
    referred to the now-deleted standalone build, and updates the comment embed_webapp.py
    inserts into the dongle-served copy to match (no more "standalone" wording anywhere).
    Regenerated webapp_html.h and rebuilt the debug APK from the cleaned source.
    The embedded blob changed by comment text only (functionally identical), so the
    flashed dongles do not need re-flashing.
2026-10-05 Web firmware flasher + verified fault clearing + 50-mile MPG
    - flash/: GitHub Pages web flasher (ESP Web Tools, Chrome/Edge over USB) with
    plain-English steps; installs the latest build without erasing NVS.
    - Firmware/tools/publish_firmware.py: stamps a date-based FW_VERSION, re-embeds
    the app, builds against the IDE sketchbook libraries and refreshes flash/.
    - FW_VERSION reported via AT@2 and shown at the bottom of the app.
    - Clear faults now waits for the ECU's real answer (44 / 7F 04 nrc / NO DATA)
    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
